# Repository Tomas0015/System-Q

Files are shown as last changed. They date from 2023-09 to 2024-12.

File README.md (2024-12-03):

# System-Q
System Q is an open source security system, based on the ESP microcontroller, with wireless and wired bus capabilities.
# I like cheese
We  hate cloud with a passion so there will not be a cloud integration developed by us, the most you will get is a GSM modem sending out SMS messages. 

 # Central control unit
-doesn't actually control anything, only contains a power supply and a battery.

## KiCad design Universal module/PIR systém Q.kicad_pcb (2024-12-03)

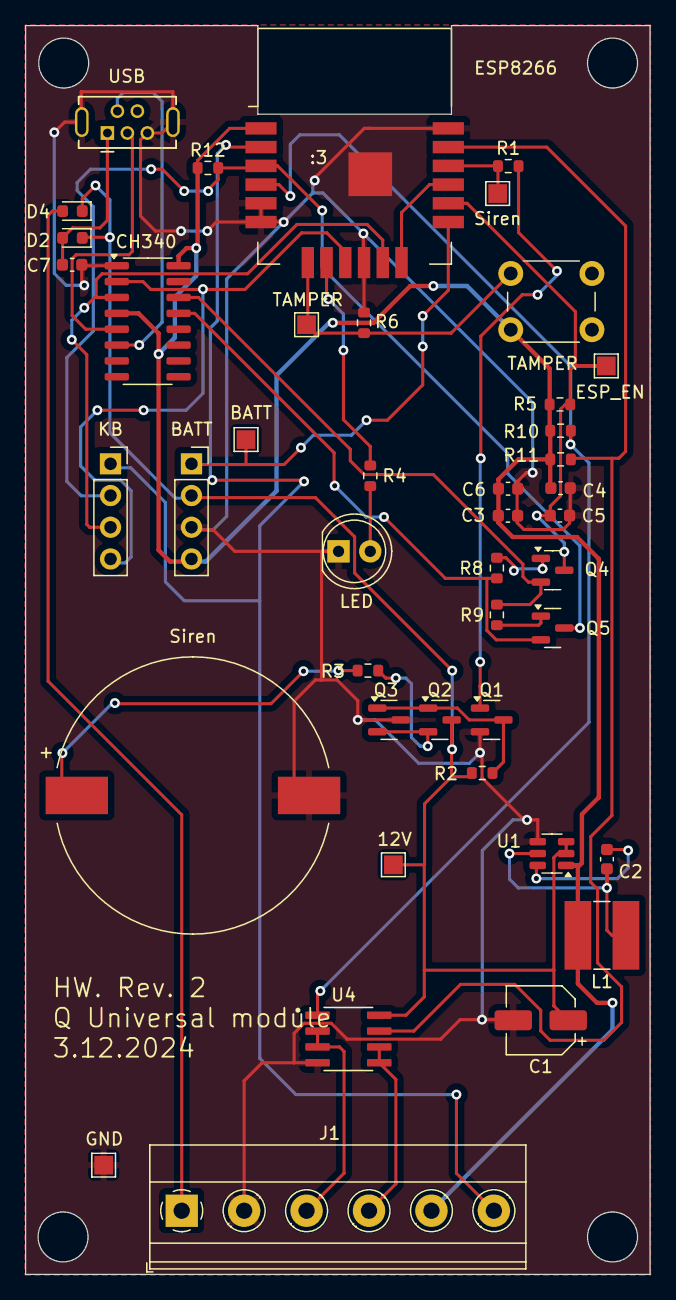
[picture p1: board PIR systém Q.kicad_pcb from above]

Board: 2 copper layers, 50.0 x 100.0 mm, 43 parts (0 on the bottom side), 32 nets.

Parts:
12V: 12V; TestPoint_Pad_1.5x1.5mm
BATT: Conn_01x04_Socket; PinSocket_1x04_P2.54mm_Vertical
BATT#2: batt test; TestPoint_Pad_1.5x1.5mm
C1: 10u 50V; CP_Elec_5x5.3
C2, C5: 100n; C_0603_1608Metric
C3, C4: 22u; C_0603_1608Metric
C6, C7: 100nF; C_0603_1608Metric
CH340: CH340C; SOIC-16_3.9x9.9mm_P1.27mm
D2, D4: D; D_0603_1608Metric
ESP8266: WT8266-S1
ESP_EN: reset test; TestPoint_Pad_1.5x1.5mm
GND: GND; TestPoint_Pad_1.5x1.5mm
J1: Screw_Terminal_01x06; TerminalBlock_Phoenix_MKDS-1,5-6_1x06_P5.00mm_Horizontal
KB: Conn_01x04_Socket; PinSocket_1x04_P2.54mm_Vertical
L1: 4u7; L_Ferrocore_DLG-0504
LED: LED - R; LED_D5.0mm
Q1, Q2: BC846; SOT-23
Q3: BC857; SOT-23
Q4, Q5: BC817; SOT-23
R1, R2, R8, R9, R10, R11, R12: 10k; R_0603_1608Metric
R3: 820; R_0603_1608Metric
R4: 100R; R_0603_1608Metric
R5: 10K; R_0603_1608Metric
R6: 4k7; R_0603_1608Metric
Siren: buzzer test; TestPoint_Pad_1.5x1.5mm
Siren#2: Siren; LPT2270AS
TAMPER: tamper switch; SW_PUSH_6mm
TAMPER#2: tamper test; TestPoint_Pad_1.5x1.5mm
U1: AP63203WU; TSOT-23-6
U4: P82B96; SOIC127P599X175-8N
USB: USB_B_Mini; USB_Mini-B_Tensility_54-00023_Vertical

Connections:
+3.3V: BATT.4, C3.1, C4.1, C6.1, CH340.4 (V3), CH340.16 (VCC), ESP8266.1 (VCC), J1.5, L1.2, R5.2, R10.1, R11.1, R12.1, TAMPER.1 (A), U1.1 (FB)
+12V: 12V.1, BATT.2, C1.1, D2.1 (K), D4.1 (K), Q2.3 (C), R2.1, U1.2 (EN), U1.3 (IN), U4.8 (VCC)
ESP_EN: C5.1, ESP8266.14 (EN), ESP_EN.1, Q4.3 (C), R5.1
GND: BATT.3, C1.2, C3.2, C4.2, C5.2, C6.2, C7.2, CH340.1 (GND), ESP8266.5 (GPIO15), ESP8266.6 (GND), ESP8266.10 (GND), ESP8266.18 (GND), ESP8266.19, GND.1, J1.2, LED.1 (K), Q1.2 (E), Q3.3 (C), R6.2, Siren#2.2 (+), U1.4 (GND), U4.4 (GND), USB.5 (GND), USB.6 (Shield)
GPIO0: ESP8266.3 (GPIO0), KB.2, Q5.3 (C), R12.2
I2C data: ESP8266.4 (GPIO2), R10.2, U4.1 (SDA)
unnamed: R3.2, Siren#2.1 (-)
unnamed: LED.2 (A), R4.2
unnamed: C7.1, D2.2 (A), USB.1 (VBUS)
unnamed: D4.2 (A), J1.1
unnamed: CH340.5 (UD+), USB.3 (D+)
unnamed: CH340.6 (UD-), USB.2 (D-)
unnamed: Q1.1 (B), R1.2
unnamed: Q1.3 (C), Q2.1 (B), Q3.1 (B), R2.2
unnamed: Q2.2 (E), Q3.2 (E), R3.1
unnamed: Q4.1 (B), R8.2
unnamed: CH340.14 (~RTS), Q4.2 (E), R9.1
unnamed: Q5.1 (B), R9.2
unnamed: CH340.13 (~DTR), Q5.2 (E), R8.1
unnamed: C2.2, U1.6 (BST)
unnamed: C2.1, L1.1, U1.5 (SW)
unnamed: ESP8266.8 (GPIO5), R4.1
unnamed: ESP8266.12 (~RST), ESP8266.15 (GPIO16)
PIR Signal: ESP8266.2 (GPIO4), J1.6, KB.1
RX: CH340.2 (TXD), ESP8266.9 (GPIO3/RXD), KB.4
SCL: J1.4, U4.5 (TXD-SCL), U4.6 (RXD-SCL)
SDA: J1.3, U4.2 (RXD-SDA), U4.3 (TXD-SDA)
TX: CH340.3 (RXD), ESP8266.11 (GPIO1/TXD), KB.3
battery voltage: BATT.1, BATT#2.1, ESP8266.13 (ADC)
buzzer signal: ESP8266.16 (GPIO12), R1.1, Siren.1
clock: ESP8266.17 (GPIO14), R11.2, U4.7 (SCL)
tamper: ESP8266.7 (GPIO13), R6.1, TAMPER.2 (B), TAMPER#2.1

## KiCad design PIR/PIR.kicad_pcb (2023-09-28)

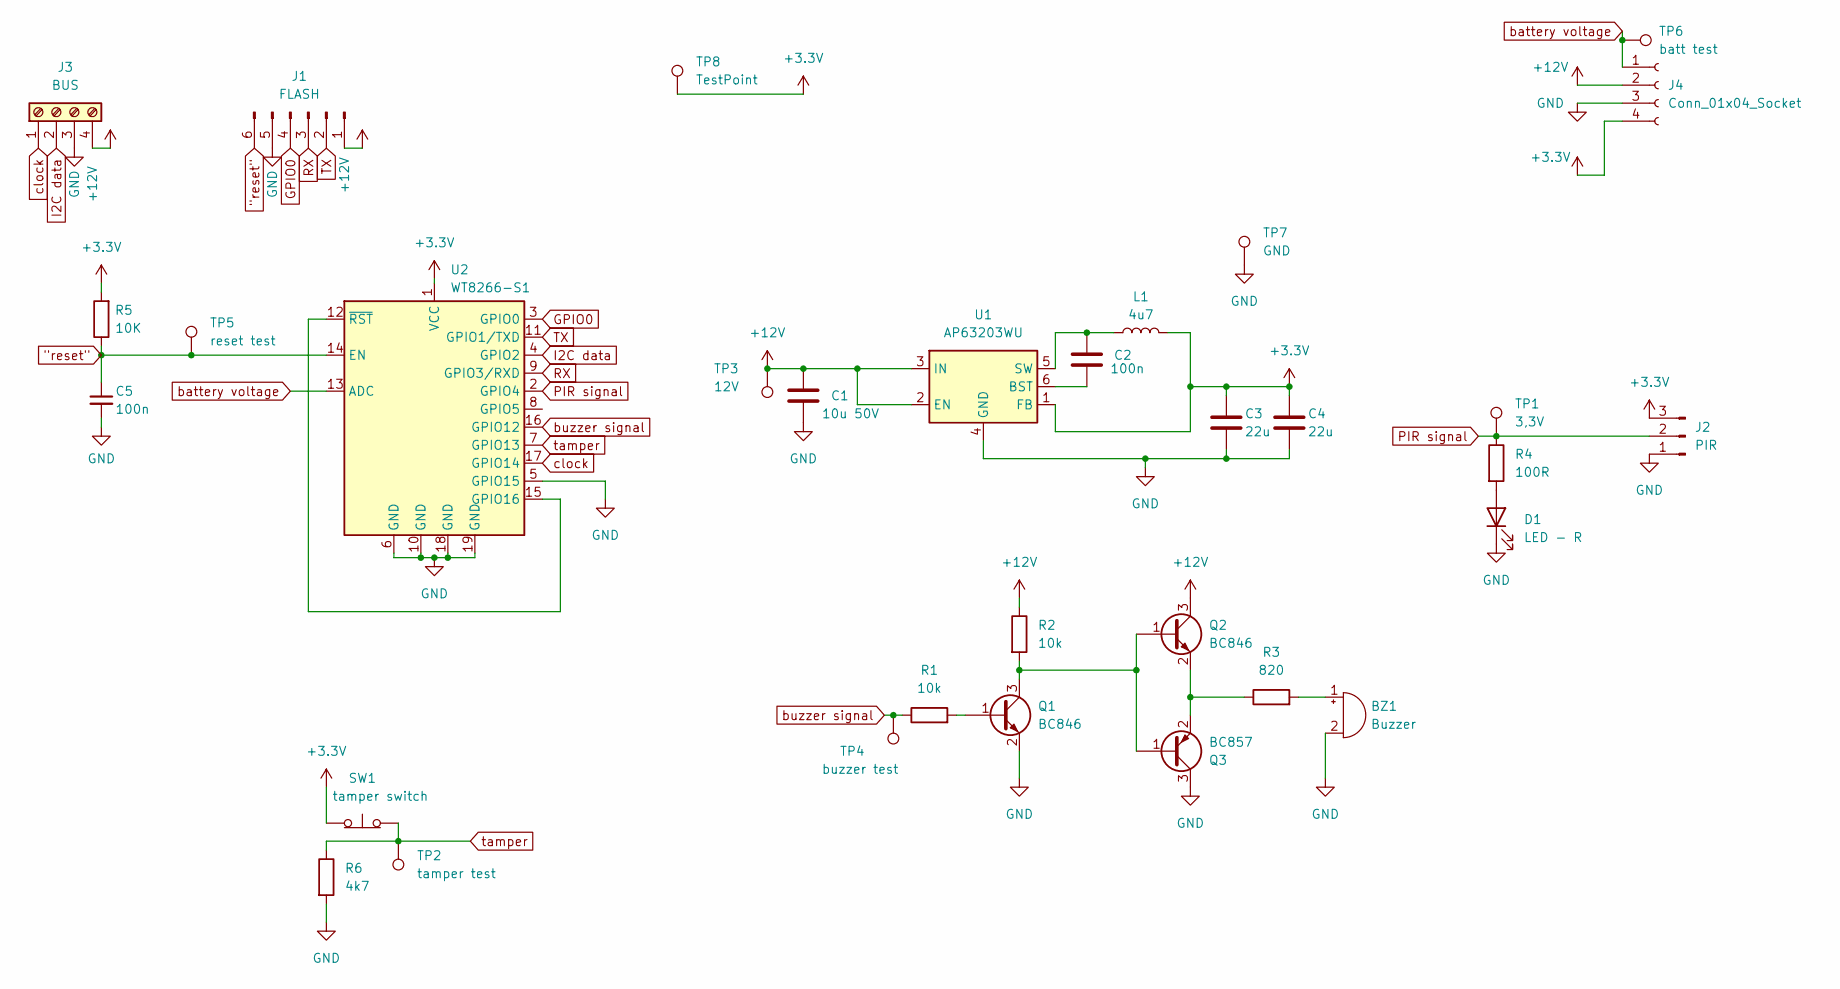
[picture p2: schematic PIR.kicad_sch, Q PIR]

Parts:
BZ1: Buzzer; LPT2270AS
C1: 10u 50V; CP_Elec_5x5.3
C2, C5: 100n; C_0603_1608Metric
C3, C4: 22u; C_0603_1608Metric
D1: LED - R; LED_D5.0mm
J1: FLASH; PinSocket_1x06_P2.54mm_Horizontal
J2: PIR; PinSocket_1x03_P2.54mm_Vertical
J3: BUS; TerminalBlock_Altech_AK300-4_P5.00mm
J4: Conn_01x04_Socket; PinSocket_1x04_P2.54mm_Horizontal
L1: 4u7; L_Ferrocore_DLG-0504
Q1, Q2: BC846; SOT-23
Q3: BC857; SOT-23
R1, R2: 10k; R_0603_1608Metric
R3: 820; R_0603_1608Metric
R4: 100R; R_0603_1608Metric
R5: 10K; R_0603_1608Metric
R6: 4k7; R_0603_1608Metric
SW1: tamper switch; SW_PUSH_6mm
TP1: 3,3V; TestPoint_Pad_1.5x1.5mm
TP2: tamper test; TestPoint_Pad_1.5x1.5mm
TP3: 12V; TestPoint_Pad_1.5x1.5mm
TP4: buzzer test; TestPoint_Pad_1.5x1.5mm
TP5: reset test; TestPoint_Pad_1.5x1.5mm
TP6: batt test; TestPoint_Pad_1.5x1.5mm
TP7: GND; TestPoint_Pad_1.5x1.5mm
TP8: TestPoint; TestPoint_Pad_1.5x1.5mm
U1: AP63203WU; TSOT-23-6
U2: WT8266-S1

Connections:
"reset": C5.1, J1.6, R5.1, TP5.1, U2.14 (EN)
+3.3V: C3.1, C4.1, J2.3, J4.4, L1.2, R5.2, SW1.1 (A), TP8.1, U1.1 (FB), U2.1 (VCC)
+12V: C1.1, J1.1, J3.4, J4.2, Q2.3 (C), R2.1, TP3.1, U1.2 (EN), U1.3 (IN)
GND: BZ1.2 (+), C1.2, C3.2, C4.2, C5.2, D1.1 (K), J1.5, J2.1, J3.3, J4.3, Q1.2 (E), Q3.3 (C), R6.2, TP7.1, U1.4 (GND), U2.5 (GPIO15), U2.6 (GND), U2.10 (GND), U2.18 (GND), U2.19 (GND)
GPIO0: J1.4, U2.3 (GPIO0)
I2C data: J3.2, U2.4 (GPIO2)
unnamed: BZ1.1 (-), R3.2
unnamed: D1.2 (A), R4.2
unnamed: Q1.1 (B), R1.2
unnamed: Q1.3 (C), Q2.1 (B), Q3.1 (B), R2.2
unnamed: Q2.2 (E), Q3.2 (E), R3.1
unnamed: C2.1, U1.6 (BST)
unnamed: C2.2, L1.1, U1.5 (SW)
unnamed: U2.12 (~RST), U2.15 (GPIO16)
PIR signal: J2.2, R4.1, TP1.1, U2.2 (GPIO4)
RX: J1.3, U2.9 (GPIO3/RXD)
TX: J1.2, U2.11 (GPIO1/TXD)
battery voltage: J4.1, TP6.1, U2.13 (ADC)
buzzer signal: R1.1, TP4.1, U2.16 (GPIO12)
clock: J3.1, U2.17 (GPIO14)
tamper: R6.1, SW1.2 (B), TP2.1, U2.7 (GPIO13)

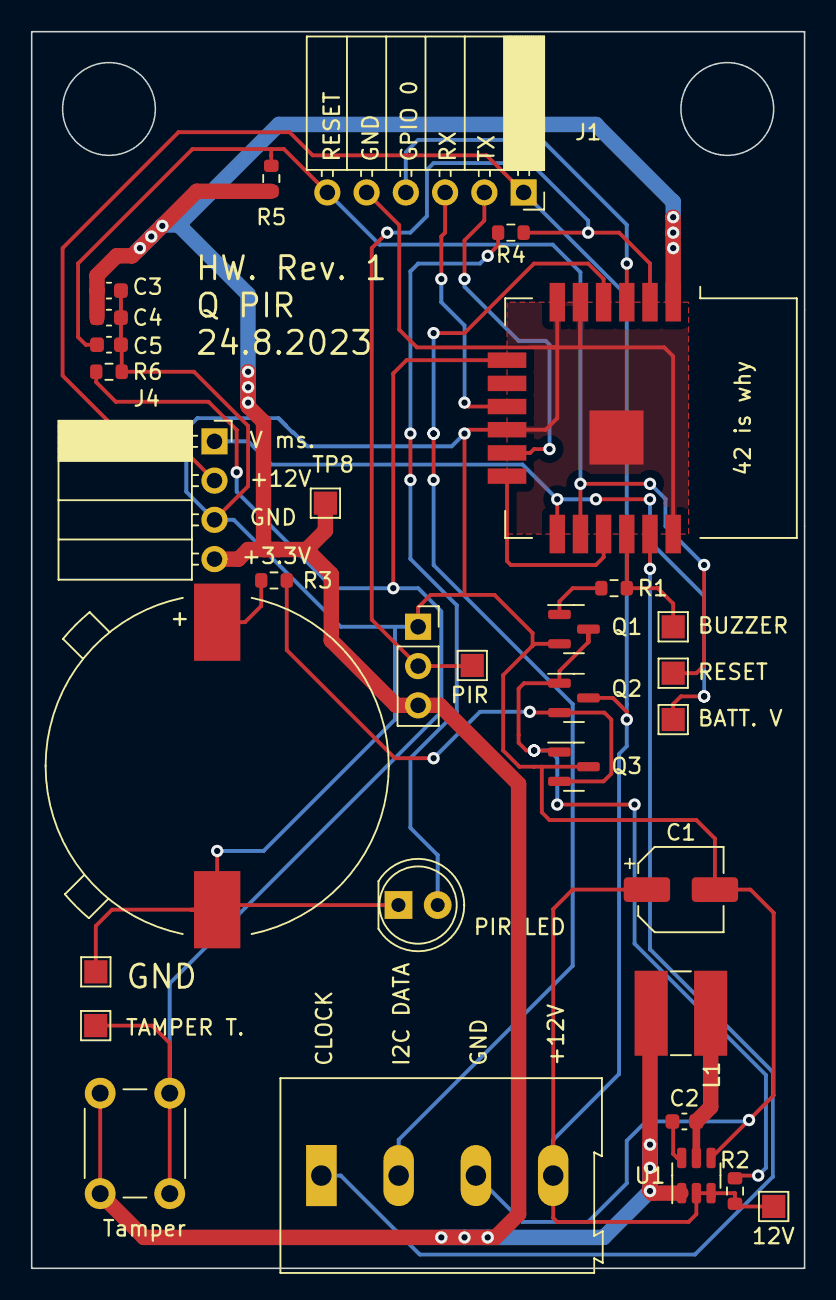
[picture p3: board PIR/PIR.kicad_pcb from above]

Board: 2 copper layers, 50.0 x 80.0 mm, 32 parts (0 on the bottom side), 21 nets.

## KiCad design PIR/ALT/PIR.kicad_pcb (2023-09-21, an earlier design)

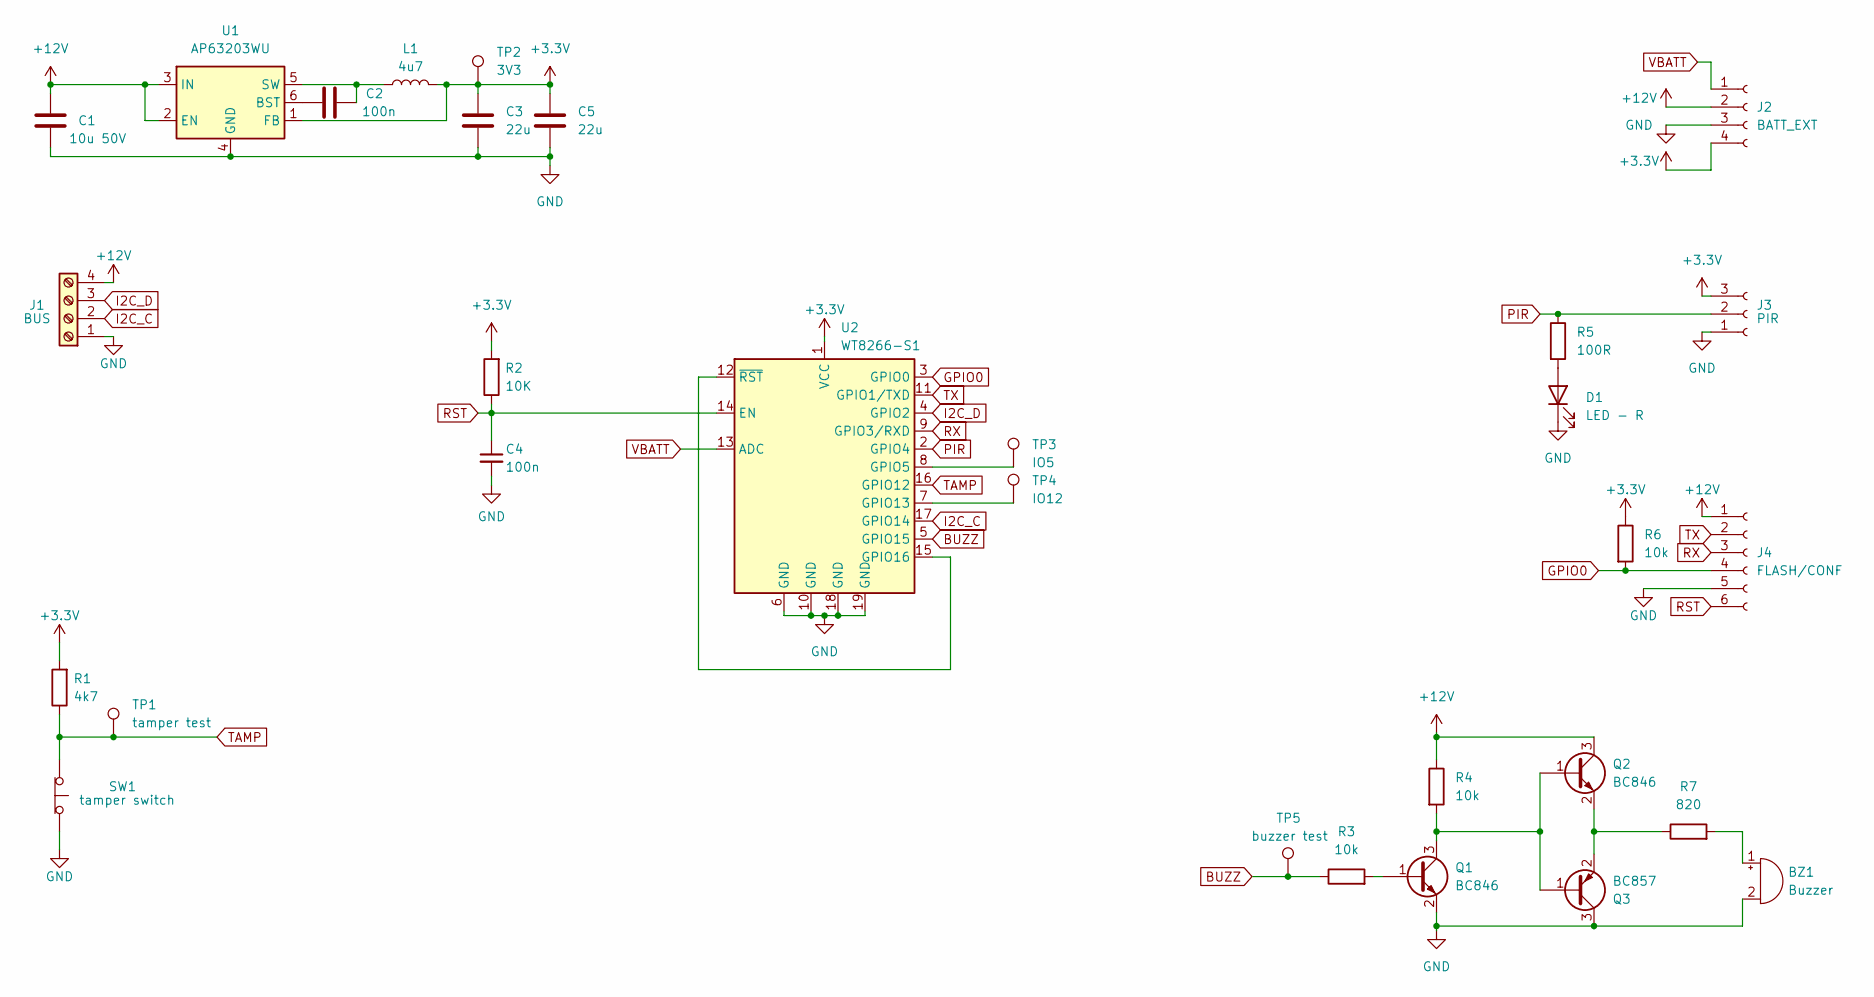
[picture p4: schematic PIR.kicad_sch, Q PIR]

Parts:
BZ1: Buzzer; LPT2270AS
C1: 10u 50V; CP_Elec_5x5.3
C2, C4: 100n; C_0603_1608Metric
C3, C5: 22u; C_0603_1608Metric
D1: LED - R; LED_D5.0mm
J1: BUS; TerminalBlock_Altech_AK300-4_P5.00mm
J2: BATT_EXT; PinSocket_1x04_P2.54mm_Horizontal
J3: PIR; PinHeader_1x03_P2.54mm_Vertical
J4: FLASH/CONF; PinSocket_1x06_P2.54mm_Horizontal
L1: 4u7; L_Ferrocore_DLG-0504
Q1, Q2: BC846; SOT-23
Q3: BC857; SOT-23
R1: 4k7; R_0603_1608Metric
R2: 10K; R_0603_1608Metric
R3, R4, R6: 10k; R_0603_1608Metric
R5: 100R; R_0603_1608Metric
R7: 820; R_0603_1608Metric
SW1: tamper switch; SW_PUSH_6mm
TP1: tamper test; TestPoint_Pad_1.5x1.5mm
TP2: 3V3; TestPoint_Pad_1.5x1.5mm
TP3: IO5; TestPoint_Pad_1.5x1.5mm
TP4: IO12; TestPoint_Pad_1.5x1.5mm
TP5: buzzer test; TestPoint_Pad_1.5x1.5mm
U1: AP63203WU; TSOT-23-6
U2: WT8266-S1

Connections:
+3.3V: C3.1, C5.1, J2.4, J3.3, L1.2, R1.2, R2.2, R6.1, TP2.1, U1.1 (FB), U2.1 (VCC)
+12V: C1.1, J1.4, J2.2, J4.1, Q2.3 (C), R4.1, U1.2 (EN), U1.3 (IN)
BUZZ: R3.1, TP5.1, U2.5 (GPIO15)
GND: BZ1.2 (+), C1.2, C3.2, C4.2, C5.2, D1.1 (K), J1.1, J2.3, J3.1, J4.5, Q1.2 (E), Q3.3 (C), SW1.2 (B), U1.4 (GND), U2.6 (GND), U2.10 (GND), U2.18 (GND), U2.19 (GND)
GPIO0: J4.4, R6.2, U2.3 (GPIO0)
I2C_C: J1.2, U2.17 (GPIO14)
I2C_D: J1.3, U2.4 (GPIO2)
unnamed: BZ1.1 (-), R7.2
unnamed: D1.2 (A), R5.2
unnamed: Q1.1 (B), R3.2
unnamed: Q1.3 (C), Q2.1 (B), Q3.1 (B), R4.2
unnamed: Q2.2 (E), Q3.2 (E), R7.1
unnamed: C2.1, U1.6 (BST)
unnamed: C2.2, L1.1, U1.5 (SW)
unnamed: TP3.1, U2.8 (GPIO5)
unnamed: TP4.1, U2.7 (GPIO13)
unnamed: U2.12 (~RST), U2.15 (GPIO16)
PIR: J3.2, R5.1, U2.2 (GPIO4)
RST: C4.1, J4.6, R2.1, U2.14 (EN)
RX: J4.3, U2.9 (GPIO3/RXD)
TAMP: R1.1, SW1.1 (A), TP1.1, U2.16 (GPIO12)
TX: J4.2, U2.11 (GPIO1/TXD)
VBATT: J2.1, U2.13 (ADC)

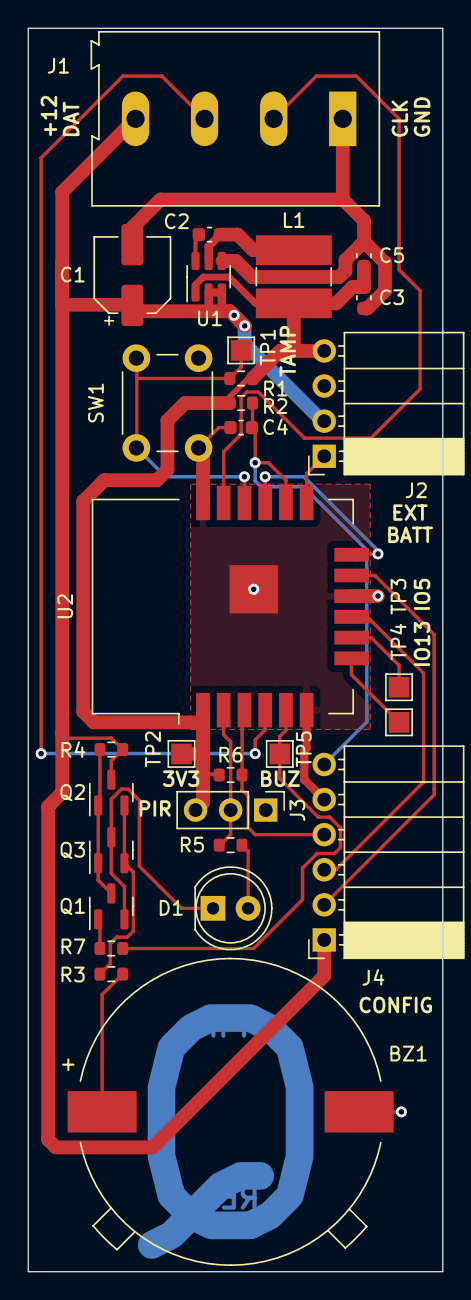
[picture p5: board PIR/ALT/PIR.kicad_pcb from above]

Board: 2 copper layers, 30.0 x 90.0 mm, 30 parts (0 on the bottom side), 23 nets.

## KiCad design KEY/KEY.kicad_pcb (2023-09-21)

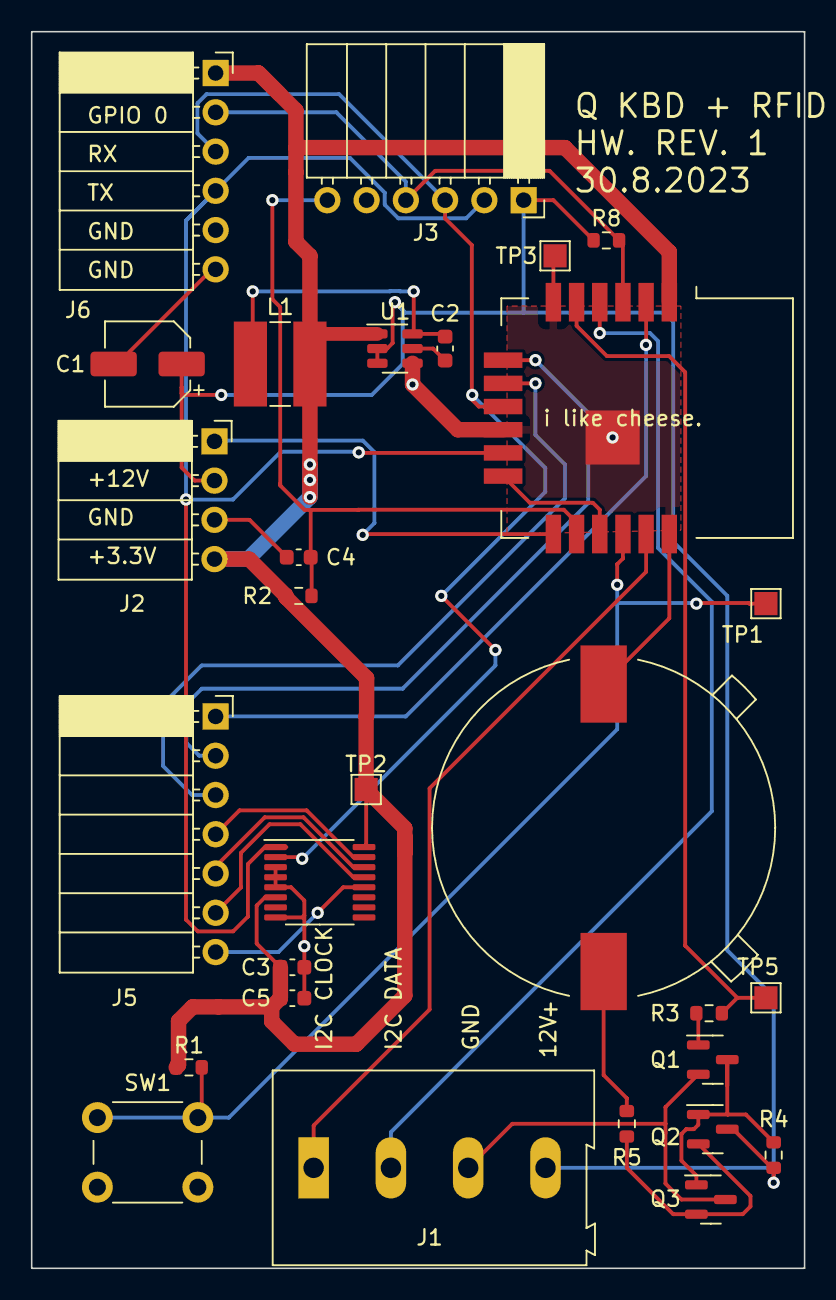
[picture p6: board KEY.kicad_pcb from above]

Board: 2 copper layers, 50.0 x 80.0 mm, 29 parts (0 on the bottom side), 26 nets.

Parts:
BZ1: Buzzer; LPT2270AS
C1: 10u 50V; CP_Elec_5x5.3
C2, C4: 100n; C_0603_1608Metric
C3, C5: 22u; C_0603_1608Metric
J1: BUS; TerminalBlock_Altech_AK300-4_P5.00mm
J2: BATT_EXT; PinSocket_1x04_P2.54mm_Horizontal
J3: FLASH/CONF; PinSocket_1x06_P2.54mm_Horizontal
J5: KEYB; PinSocket_1x07_P2.54mm_Horizontal
J6: RFID; PinSocket_1x06_P2.54mm_Horizontal
L1: 4u7; L_Ferrocore_DLG-0504
Q1, Q2: BC846; SOT-23
Q3: BC857; SOT-23
R1, R2, R8: 10K; R_0603_1608Metric
R3, R4: 10k; R_0603_1608Metric
R5: 820; R_0603_1608Metric
SW1: tamper switch; SW_PUSH_6mm
TP1: tamper test; TestPoint_Pad_1.5x1.5mm
TP2: 3V3; TestPoint_Pad_1.5x1.5mm
TP3: TestPoint; TestPoint_Pad_1.5x1.5mm
TP5: buzzer test; TestPoint_Pad_1.5x1.5mm
U1: AP63203WU; TSOT-23-6
U2: WT8266-S1
U3: 74LVC138; TSSOP-16_4.4x5mm_P0.65mm

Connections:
+3.3V: C3.1, C5.1, J2.4, J6.1, L1.2, R1.1, R2.2, TP2.1, U1.1 (FB), U2.1 (VCC), U3.6 (E3), U3.16 (VCC)
+12V: C1.1, J1.4, J2.2, J3.1, Q2.3 (C), R4.1, R8.1, U1.2 (EN), U1.3 (IN)
BUZZ: R3.1, TP5.1, U2.5 (GPIO15)
GND: BZ1.2 (+), C1.2, C3.2, C4.2, C5.2, J1.3, J2.3, J3.5, J6.5, J6.6, Q1.2 (E), Q3.3 (C), SW1.2 (B), TP3.1, U1.4 (GND), U2.6 (GND), U2.10 (GND), U2.18 (GND), U2.19 (GND), U3.3 (A2), U3.4 (E1), U3.5 (E2), U3.8 (GND)
GPIO0: J3.4, J6.2, R8.2, U2.3 (GPIO0)
I2C_C: J1.1, U2.17 (GPIO14)
I2C_D: J1.2, U2.4 (GPIO2)
unnamed: BZ1.1 (-), R5.2
unnamed: J5.4, U3.15 (O0)
unnamed: J5.5, U3.14 (O1)
unnamed: J5.6, U3.13 (O2)
unnamed: J5.7, U3.12 (O3)
unnamed: Q1.1 (B), R3.2
unnamed: Q1.3 (C), Q2.1 (B), Q3.1 (B), R4.2
unnamed: Q2.2 (E), Q3.2 (E), R5.1
unnamed: C2.2, L1.1, U1.6 (BST)
unnamed: C2.1, U1.5 (SW)
unnamed: U2.12 (~RST), U2.15 (GPIO16)
RST: C4.1, J3.6, R2.1, U2.14 (EN)
RX: J3.3, J6.3, U2.9 (GPIO3/RXD), U3.2 (A1)
TAMP: R1.2, SW1.1 (A), TP1.1, U2.16 (GPIO12)
TX: J3.2, J6.4, U2.11 (GPIO1/TXD), U3.1 (A0)
VBATT: J2.1, U2.13 (ADC)
Y0: J5.1, U2.2 (GPIO4)
Y1: J5.2, U2.7 (GPIO13)
Y2: J5.3, U2.8 (GPIO5)

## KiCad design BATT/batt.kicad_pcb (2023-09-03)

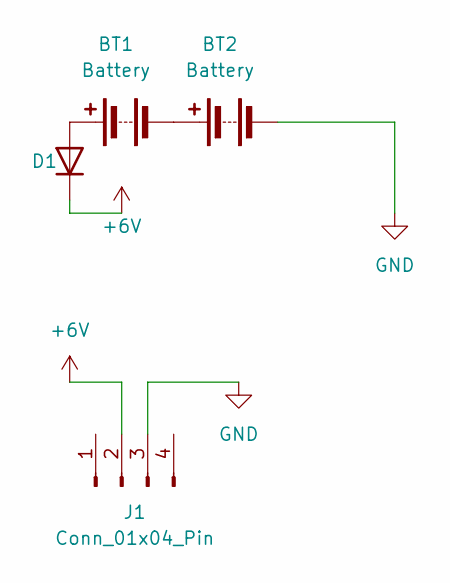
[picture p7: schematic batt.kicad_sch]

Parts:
BT1, BT2: Battery; BatteryHolder_Keystone_2468_2xAAA
D1: D; D_A-405_P10.16mm_Horizontal
J1: Conn_01x04_Pin; PinHeader_1x04_P2.54mm_Vertical

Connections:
+6V: D1.1 (K), J1.2
GND: BT2.2 (-), J1.3
unnamed: BT1.1 (+), D1.2 (A)
unnamed: BT1.2 (-), BT2.1 (+)

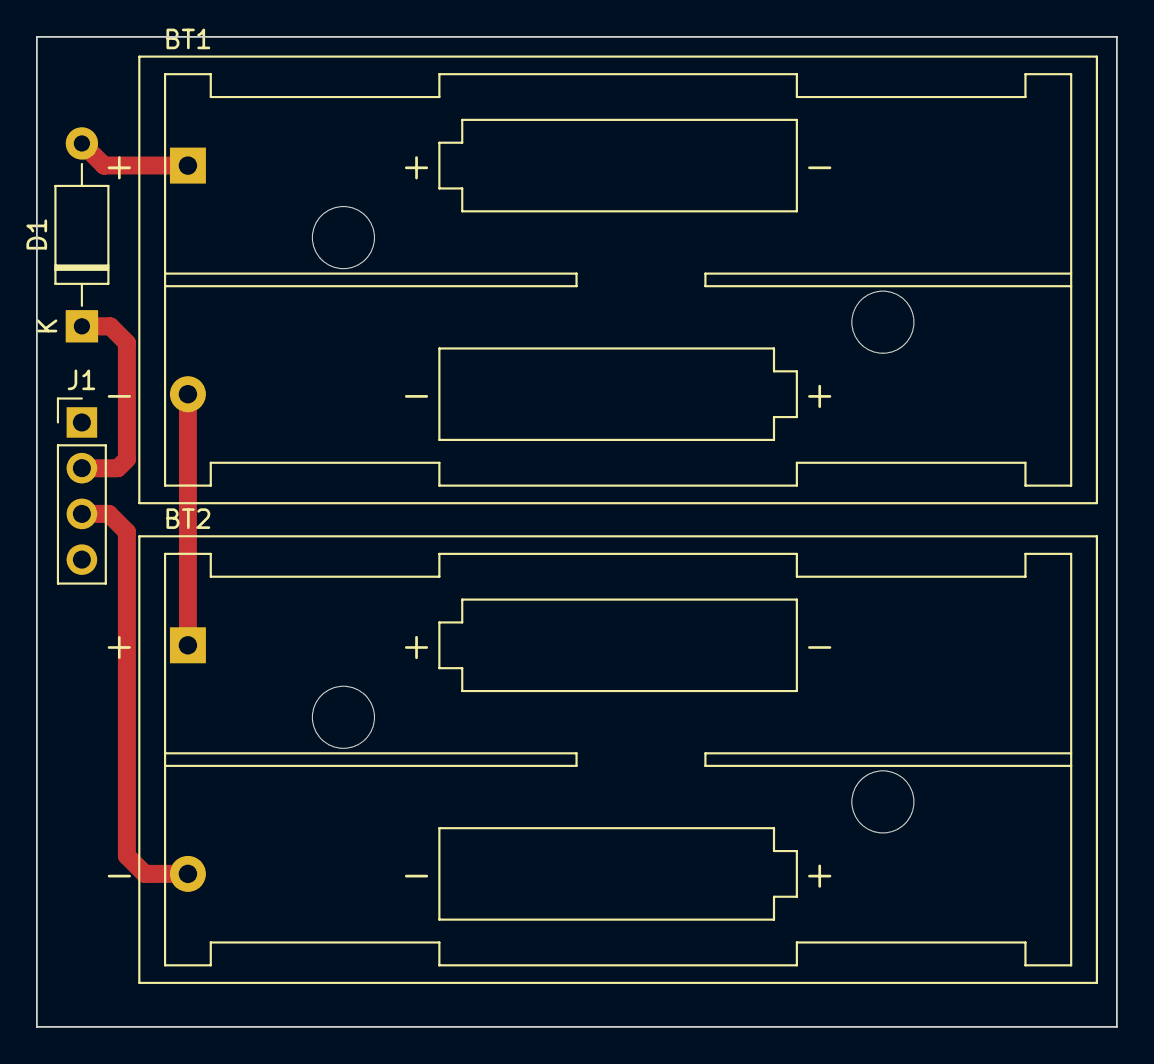
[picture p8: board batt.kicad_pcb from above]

Board: 2 copper layers, 60.0 x 55.0 mm, 4 parts (0 on the bottom side), 4 nets.

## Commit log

2023-08-30 initail commit
    [KEY.kicad_sch, PIR.kicad_pcb, PIR.kicad_sch]
2023-08-30 Add pcb design
    [KEY.kicad_pcb]
2023-08-30 Wires are cool
2023-08-30 Enhance PCB design
    [KEY.kicad_pcb]
2023-09-03 Add files via upload
    first version of the schematic for the backup battery
    [batt.kicad_pcb, batt.kicad_sch]
2023-09-07 upgrades people, upgrades!
    [PIR.kicad_pcb]
2023-09-21 Add ground pad to WT8266
2023-09-21 Update symbol and footprint of WT8266
    [KEY.kicad_pcb, KEY.kicad_sch, PIR.kicad_pcb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]
2023-09-21 Fix incident
    [PIR.kicad_pcb, PIR.kicad_sch]
2024-10-30 Add files via upload
    better PCB design
    [PIR systém Q.kicad_pcb, PIR systém Q.kicad_sch]
2024-10-30 create og universal module design
    [PIR systém Q.kicad_pcb, PIR systém Q.kicad_sch]
2024-10-31 better diode
    [PIR systém Q.kicad_sch]
2024-11-16 add features
    [PIR systém Q.kicad_sch]
2024-11-17 better design
    [PIR systém Q.kicad_sch]
2024-11-24 begun the drawing of the PCB, fixed libraries
    [PIR systém Q.kicad_pcb, PIR systém Q.kicad_sch, PIR systém Q_old.kicad_pcb]
2024-12-01 basic PCB design
    [PIR systém Q.kicad_pcb, PIR systém Q.kicad_sch]
2024-12-03 finish PCB design, bonus gerber files
    [PIR systém Q.kicad_pcb, PIR systém Q.kicad_sch]
2024-12-03 fix small issues
    [PIR systém Q.kicad_pcb]
